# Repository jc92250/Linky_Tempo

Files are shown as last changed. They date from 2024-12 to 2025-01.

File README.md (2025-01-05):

# Linky_Tempo
Délestage fil pilote

L'objectif de ce petit montage est de délester mon chauffage électrique (via ses fils pilote):
- en période HPJR (heure pleine jour rouge)
- en période HPJW (heure pleine jour blanc) avec possibilité d'annuler le délestage
- en cas de surconsommation

L'arduino est connecté à la sortie TIC (télé-information client) du compteur Linky.
Le compteur doit être configuré en mode "Historique" (c'est son mode par défaut)
Parmi les informations reçues, on s'intéresse:
- à la période en cours de l'abonnement Tempo
- à la consommation instantanée

Lorsque la période en cours est HPJR (heure pleine jour rouge), l'Arduino envoie un signal de délestage aux fils pilote des radiateurs.
Durant cette période, il n'y a aucun moyen d'annuler ce délestage.

Lorsque la période en cours est HPJW (heure pleine jour blanc), l'Arduino envoie également un signal de délestage aux fils pilote des radiateurs.
Durant cette période, il est possible d'annuler le délestage via un appui sur le bouton poussoir.
Le délestage est alors annulé jusqu'à la fin de la période HPJW (typiquement, dès que le compteur passe en heure creuse)
Un second appui sur le bouton poussoir réactive le délestage.
Ce bouton poussoir n'a d'effet qu'en période HPJW.

Par ailleurs, le délestage peut également être activé lors d'une surconsomation (typiquement, si un four et des plaques électriques sont allumés alors que le chauffage est par ailleur activé)
Ce délestage intervient dès que la consommation électrique instantanée atteint 80% de la puissance souscrite.

Lorsque le délestage est activé, il dure au minimum 4mn (pour tenir compte de l'aspect intermittent de la consommation électrique d'un four ou d'une plaque électrique)

Le fichier config.h définit les paramètres dont les valeurs peuvent être ajustées.

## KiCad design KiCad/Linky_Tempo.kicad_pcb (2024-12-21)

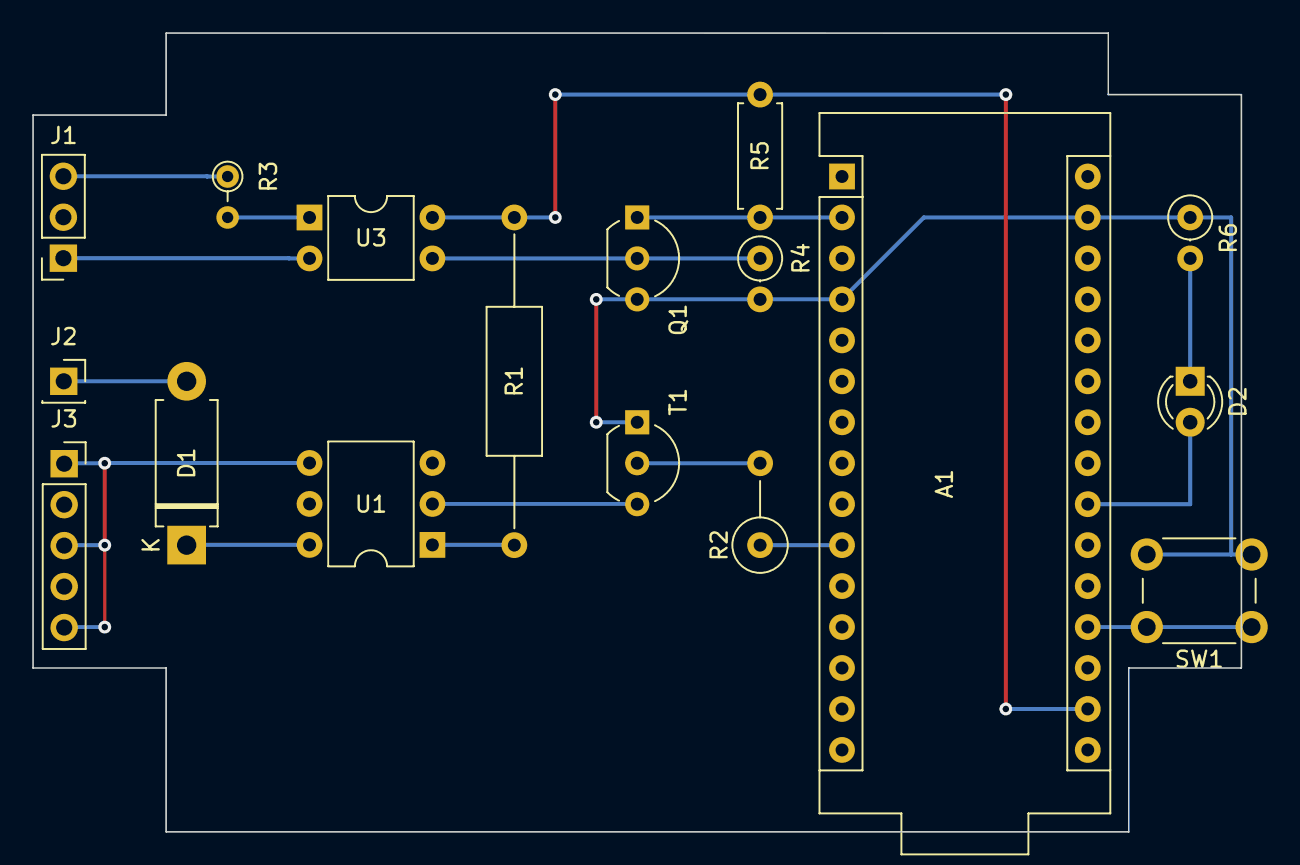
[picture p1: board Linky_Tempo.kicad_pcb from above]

Board: 2 copper layers, 74.9 x 49.5 mm, 17 parts (0 on the bottom side), 15 nets.

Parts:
A1: Arduino_Nano_Socket; Arduino_Nano
D1: 1N4007; D_DO-15_P10.16mm_Horizontal
D2: LED; LED_D3.0mm
J1: TIC; PinSocket_1x03_P2.54mm_Vertical
J2: Main; PinSocket_1x01_P2.54mm_Vertical
J3: FP; PinSocket_1x05_P2.54mm_Vertical
Q1: BS170; TO-92_Inline_Wide
R1: 110Ω; R_Axial_DIN0309_L9.0mm_D3.2mm_P20.32mm_Horizontal
R2: 1.5kΩ; R_Axial_DIN0309_L9.0mm_D3.2mm_P5.08mm_Vertical
R3: 2,2kΩ; R_Axial_DIN0204_L3.6mm_D1.6mm_P2.54mm_Vertical
R4: 10kΩ; R_Axial_DIN0207_L6.3mm_D2.5mm_P2.54mm_Vertical
R5: 10kΩ; R_Axial_DIN0207_L6.3mm_D2.5mm_P7.62mm_Horizontal
R6: 1kΩ; R_Axial_DIN0207_L6.3mm_D2.5mm_P2.54mm_Vertical
SW1: SW_Push; SW_PUSH_6mm
T1: 2N2222; TO-92_Inline_Wide
U1: MOC3041M; DIP-6_W7.62mm
U3: LTV-814; DIP-4_W7.62mm

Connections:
+3V3: A1.17 (3V3), R1.1, R5.1, U3.4
/I1: J1.1, U3.2
/I2: J1.3, R3.1
Earth: A1.4 (GND), A1.29 (GND), Q1.3 (S), R4.2, R6.1, SW1.2, T1.1 (E)
unnamed: A1.2 (D0/RX), Q1.1 (D), R5.2
unnamed: A1.10 (D7), R2.1
unnamed: D1.2 (A), J2.1
unnamed: D1.1 (K), U1.6
unnamed: D2.1 (K), R6.2
unnamed: J3.1, J3.3, J3.5, U1.4
unnamed: Q1.2 (G), R4.1, U3.3
unnamed: R1.2, U1.1
unnamed: R3.2, U3.1
unnamed: R2.2, T1.2 (B)
unnamed: T1.3 (C), U1.2

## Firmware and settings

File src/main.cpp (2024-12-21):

//
// ---------------------------------------------------------------- 
// Programme de délestage
// Inputs: les données de la TIC, données envoyées par le compteur
//         Linky
// Output: la commande du fil pilote en mode Hors-gel
//
// Pour minimiser la consommtion, on ne va utiliser que la LED intégrée.
// Elle va clignoter rapidement lors de la lecture initiale de la TIC en vue
// de déterminer si on est en mode "historique" ou en mode "standard".
// Si on est en mode "standard", vu qu'on ne supporte pas ce mode, la LED va
// alors flasher deux fois ("non non") toutes les deux secondes indéfiniment.
// Il faudra faire un RESET de l'arduino pour déclancher une nouvelle détection.
// Si on est en mode "historique" qui est le mode supporté, il y a deux cas:
// - nominal: la LED reste éteinte
// - délestage pour cause de HPJW ou HPJR: la LED clignote
// - délestage pour cause de surconsommation: la LED clignote
//
// TODO: implifier le code de LibTeleInfo pour ne conserver que les
//       infos utiles de la TIC (pour économiser de la RAM)
// TODO: temporisation à l'allumage (si on ne branche pas tout en
//       même temps pour ce qui est de I1, I2 et A)
//       faire cela dans le setup_test_led par exemple, en faisant
//       clignoter les deux LEDs en alternance
// TODO: initialiser la sortie fil pilote en hors-gel ?
// TODO: que se passe t-il si l'ensemble des radiateurs seuls
//       provoque un délestage?
//       ce n'est pas possible car l'ensemble fait 4500W
//       séjour  = 1000W + 1500W
//       bureau  = 1000W
//       chambre = 1000W
// TODO: définir de quelles LEDs on a besoin
//       - trame reçue (qui confirme qu'on est bien connecté à la TIC)
//       - délestage en JPJW ou HPJR
//       - délestage car surconsommation
// TODO: fiabiliser la détection du mode histo
//       (quid si I1-I2 ne sont pas branchés lors de la détection)
//       éventuellement, hardcoder le mode histo
// TODO: vérifier que ça marche si
//       1) histo est hardcodé et
//       2) I1-I2 sont branchés plus tard
// ---------------------------------------------------------------- 
//
#include <Arduino.h>
#include "LED.h"
#include "LibTeleinfo.h"
#include "setup_detect_TIC_mode.h"
#include "callbacks.h"

// ---------------------------------------------------------------- 
// Gestion de la TIC
// Le flux d'info est reçu via le Serial (port RX)
// ---------------------------------------------------------------- 

// Dans quel mode est la TIC (standard ou historique ?) 
_Mode_e mode_tic;

// L'objet qui permet de récupérer le détail de la TIC
// Plus d'info ici: https://hallard.me/libteleinfo/
TInfo tinfo;

// ---------------------------------------------------------------- 
// Commande des fils pilote
// ---------------------------------------------------------------- 
#define PIN_PILOTE 7


// ---------------------------------------------------------------- 
// Annulation du délestage Jour Blanc:
// Par défaut, on déleste en HPJW
// Un bouton permet d'annuler ce délestage
// Cette annulation n'est effective que si on est déjà en délestage
// Et elle court jusqu'à la prochaine heure creuse
// Si on ré-appuie, on déleste à nouveau
// Une LED jaune allumée indique qu'on n'est pas en délestage
// La LED est manipulée via LED_ANNUL_ON et LED_ANNUL_OFF
//
// PIN_BTN_ANNUL: Le bouton permettant d'annuler le délestage HPJW
//                Il mets à la masse cette entrée
// annulDelestageHPJW: false par défaut
//                     passe à true si l'utilisateur clicke le btn
//                     repasse à false au prochain click
//                     passe à false à la prochaine HP
// debounce: qd a été observé le dernier changement d'état du btn
//           tout changement dans les 0,5sec qui suivent sera ignoré
// ---------------------------------------------------------------- 
#define PIN_BTN_ANNUL 14
bool annulDelestageHPJW;
uint32_t debounce;

// ---------------------------------------------------------------- 
// setup des différentes pins de l'arduino
// - en input pour la TIC
// - en output pour la commande des fils pilote
// ---------------------------------------------------------------- 
void setup_pins() {

  // Commande des fils pilote
  pinMode(PIN_PILOTE, OUTPUT);
  // Les LED
  pinMode(LED_DETECT, OUTPUT);
  pinMode(LED_STD, OUTPUT);
  pinMode(LED_HIST, OUTPUT);
  pinMode(LED_ANNUL, OUTPUT);
  // Le bouton
  pinMode(PIN_BTN_ANNUL, INPUT_PULLUP);
}

// ---------------------------------------------------------------- 
// setup
// ---------------------------------------------------------------- 
void setup() {

  setup_pins();
  setup_LED();
  
  // init interface série suivant mode TIC
  // TODO: forcer le mode historique car:
  // - on sait qu'on est en mode historique
  // - on ne veut pas prendre le risque que le code bascule en standard si la détection du mode historique échoue
	mode_tic = setup_detect_TIC_mode();

  // On ne supporte que le mode "historique"
  // Si on n'arrive pas à détecter ce mode, on ne peut rien faire
  if (mode_tic != TINFO_MODE_HISTORIQUE) {
    // On ne supporte pas le mode standard
    LED_STD_ON();
    // On se met en mode Hors-gel pour limiter la consommation
    digitalWrite(PIN_PILOTE, HIGH); // TODO: LOW or HIGH
    // Et la LED rouge va flasher indéfiniment pour montrer le problème
    LED_Flashx2Forever();
  }
  LED_HIST_ON();

   // init interface TIC
  tinfo.init(mode_tic);

  // soyons appelés lorsqu'on a reçu une nouvelle trame
  tinfo.attachADPS(AttachADPSCallback); // TODO: utile ?
  tinfo.attachUpdatedFrame(UpdatedFrameCallback);
  tinfo.attachData(AttachDataCallback);

  // on déleste en HPJW par défaut
  annulDelestageHPJW = false;
  debounce = millis();
}

// ---------------------------------------------------------------- 
// loop
// ---------------------------------------------------------------- 
// Si délestage, c'est depuis quand, basé sur milli()
uint32_t startDelestage;

void loop() {
  uint32_t currentTime = millis();

  // réception d'un caractère de la TIC
  // on laisse tinfo essayer de décoder l'ensemble
  if (Serial.available()) tinfo.process(Serial.read());

  // On ne peut annuler le délestage qu'en HPJW
  // On s'assure donc que ette annulation ne reste pas active trop longtemps
  if (!delestage_HPJW) annulDelestageHPJW = false;

  // pression sur le bouton ?
  // le bouton n'est actif qu'en HPJW
  if (delestage_HPJW) {
    if (currentTime - debounce > TEMPS_DEBOUNCE) {
      if (digitalRead(PIN_BTN_ANNUL) == LOW) { // bouton pressé
        // on bascule l'annulation ou non du délestage HPJW
        debounce = currentTime;
        annulDelestageHPJW = !annulDelestageHPJW;
      }
    }
  }

  // on indique (via la LED dédiée) si on déleste ou pas en HPJW
  digitalWrite(LED_ANNUL, annulDelestageHPJW ? HIGH : LOW);

  // on indique au fil pilote si on déleste ou pas
  if ((delestage_HPJW && !annulDelestageHPJW) || delestage_HPJR || delestage_CONSO) {
    // On doit délester
    LED_Flashx1Lent();
    digitalWrite(PIN_PILOTE, HIGH);
    // En on repousse la fin du délestage
    startDelestage = currentTime;
    // Comme on ne sait pas si on était déjà en mode délestage, on définit les pins de sortie en conséquence
  } else if (currentTime - startDelestage > TEMPS_DELESTAGE) {
    // On n'a plus besoin de délester
    // et ceci, depuis assez longtemps (TEMPS_DELESTAGE)
    // Ce temps d'attente est pour éviter de basculer trop souvent
    // Par exemple, lorsque le four ou une plaque de cuisson est en maintient de température
    // On peut enfin annuler le délestage
    LED_Eteinte();
    digitalWrite(PIN_PILOTE, LOW);
  }
 /*!delestage_HPJR && !delestage_CONSO &&*/ 
}

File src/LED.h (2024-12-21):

#ifndef LED_h
#define LED_h

#include <Arduino.h>

// ---------------------------------------------------------------- 
// Les différentes LEDs
// (en plus de la led builtin)
// Note: elles ne sont pas forcément connectées à l'Arduino
// (la construction minimale n'a que la led builtin)
// ---------------------------------------------------------------- 
#define LED_DETECT 10 // allumée lors de la détection du mode de la TIC
#define LED_HIST 5    // allumée si TIC en mode historique (le seul mode qu'on supporte)
#define LED_STD 8     // allumée si TIC en mode standard (on ne le supporte pas)

#define LED_ANNUL 17  // allumée si on a annulé le délestage

// ----------------------------------------------------------------
// Initialization
// ----------------------------------------------------------------
void setup_LED() {
  digitalWrite(LED_BUILTIN, LOW);
  digitalWrite(LED_DETECT, LOW);
  digitalWrite(LED_HIST, LOW);
  digitalWrite(LED_STD, LOW);
  digitalWrite(LED_ANNUL, LOW);
}

void LED_DETECT_ON() {
  digitalWrite(LED_DETECT, HIGH);
}
void LED_DETECT_OFF() {
  digitalWrite(LED_DETECT, LOW);
}
void LED_HIST_ON() {
  digitalWrite(LED_HIST, HIGH);
}
void LED_STD_ON() {
  digitalWrite(LED_STD, HIGH);
}
void LED_ANNUL_ON() {
  digitalWrite(LED_ANNUL, HIGH);
}
void LED_ANNUL_OFF() {
  digitalWrite(LED_ANNUL, LOW);
}
// ----------------------------------------------------------------
// Gestion de la LED_BUILTIN
// - elle va basculer durant la détection du mode de la TIC
// - elle va clignoter indéfiniment deux fois toutes les deux
//   secondes si la TIC n'est pas dans le mode "historique"
// - elle va flasher une fois toutes les deux secondes si le
//   délestage est activé
// ----------------------------------------------------------------

void LED_Flashx2Forever() {
    while(true) {
      digitalWrite(LED_BUILTIN, HIGH);
      delay(10);
      digitalWrite(LED_BUILTIN, LOW);
      delay(100);
      digitalWrite(LED_BUILTIN, HIGH);
      delay(10);
      digitalWrite(LED_BUILTIN, LOW);
      delay(2000);
    }
}

void LED_Flashx1Lent() {

}

void LED_Eteinte() {
  digitalWrite(LED_BUILTIN, LOW);
}

#endif
